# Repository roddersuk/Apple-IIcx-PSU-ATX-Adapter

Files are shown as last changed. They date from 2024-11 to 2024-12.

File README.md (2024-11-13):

# Apple-IIcx-PSU-ATX-Adapter
Apple Mac IIcx PSU ATX Adapter

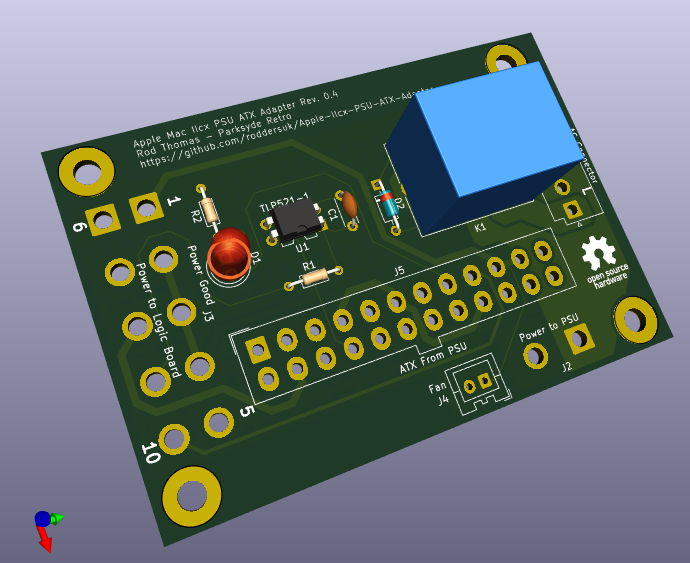
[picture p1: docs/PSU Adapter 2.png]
ATX Adapter PCB

 
The PSU in these old computers suffer with age, particularly the Rifa capacitors which have a tendency to explode.
The general consensus seems to be that it isn't worth trying to repair them as this is likely to only extend their life by a few years.
I therefore decided to replace the guts of the PSU with a mini ATX PSU but there are a couple of issues with hooking it up:
1) The Apple PSU has a special connector to the logic board allowing the PSU to be plugged in as a unit.
2) The ATX PSU does not have direct provision for the soft start capability.
3) Many ATX units don't have a monitor A/C pass-through

I decided to design this PCB to solve all of these issues. It is designed to connect to the power plug from the mains input unit, pass AC power 
to the ATX board, get DC power back via the ATX connector and use the logic board plug and wires from the old PSU.

The ATX PSU I have used is from FSP Group Inc. Model FSP270-60LE as this has comparable power output capabilities.

I have also designed a mounting plate for the ATX PCB which can be 3D printed.

See files in Docs for the schematic and details of the build.

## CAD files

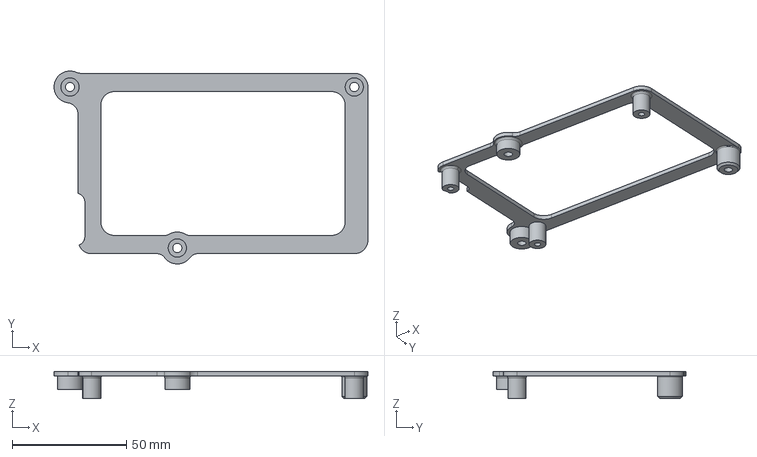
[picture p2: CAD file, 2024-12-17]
PSU Mounting Plate.step
137.5 x 84.5 x 12.0 mm

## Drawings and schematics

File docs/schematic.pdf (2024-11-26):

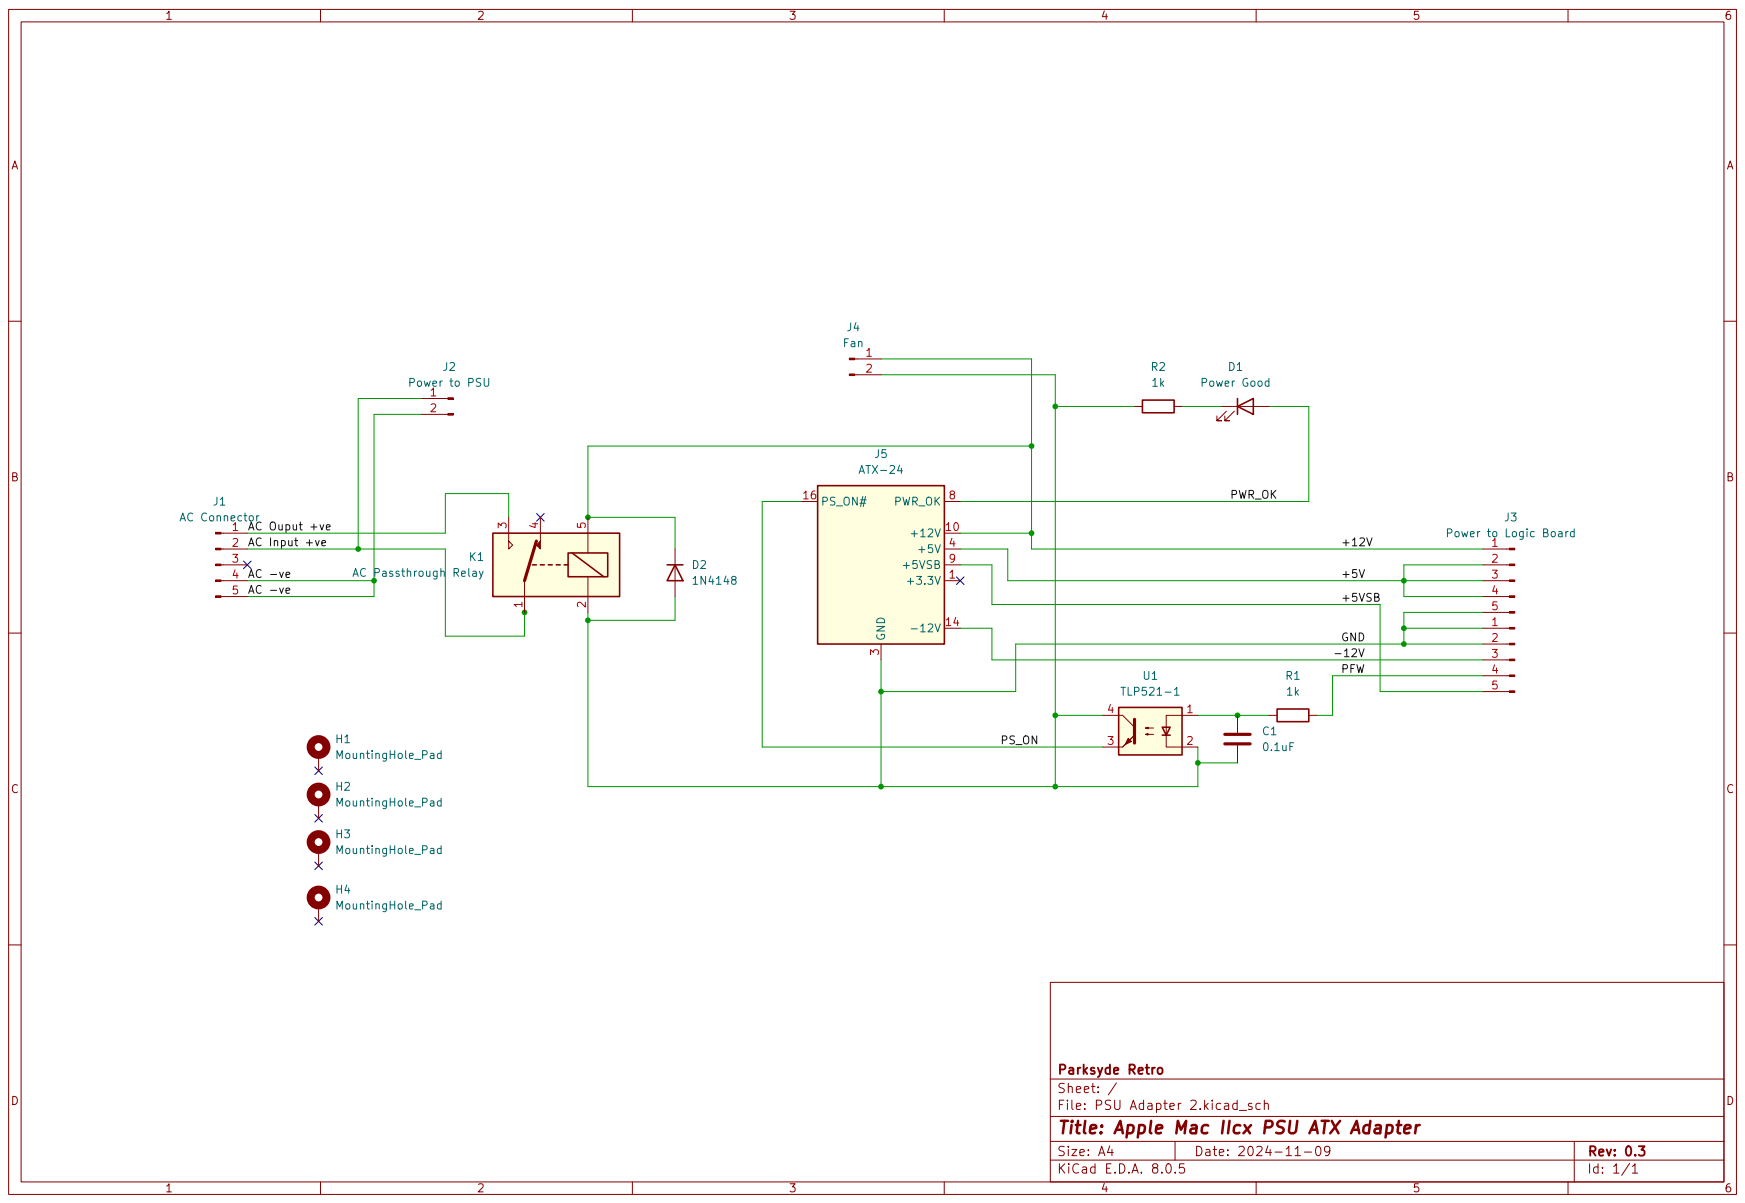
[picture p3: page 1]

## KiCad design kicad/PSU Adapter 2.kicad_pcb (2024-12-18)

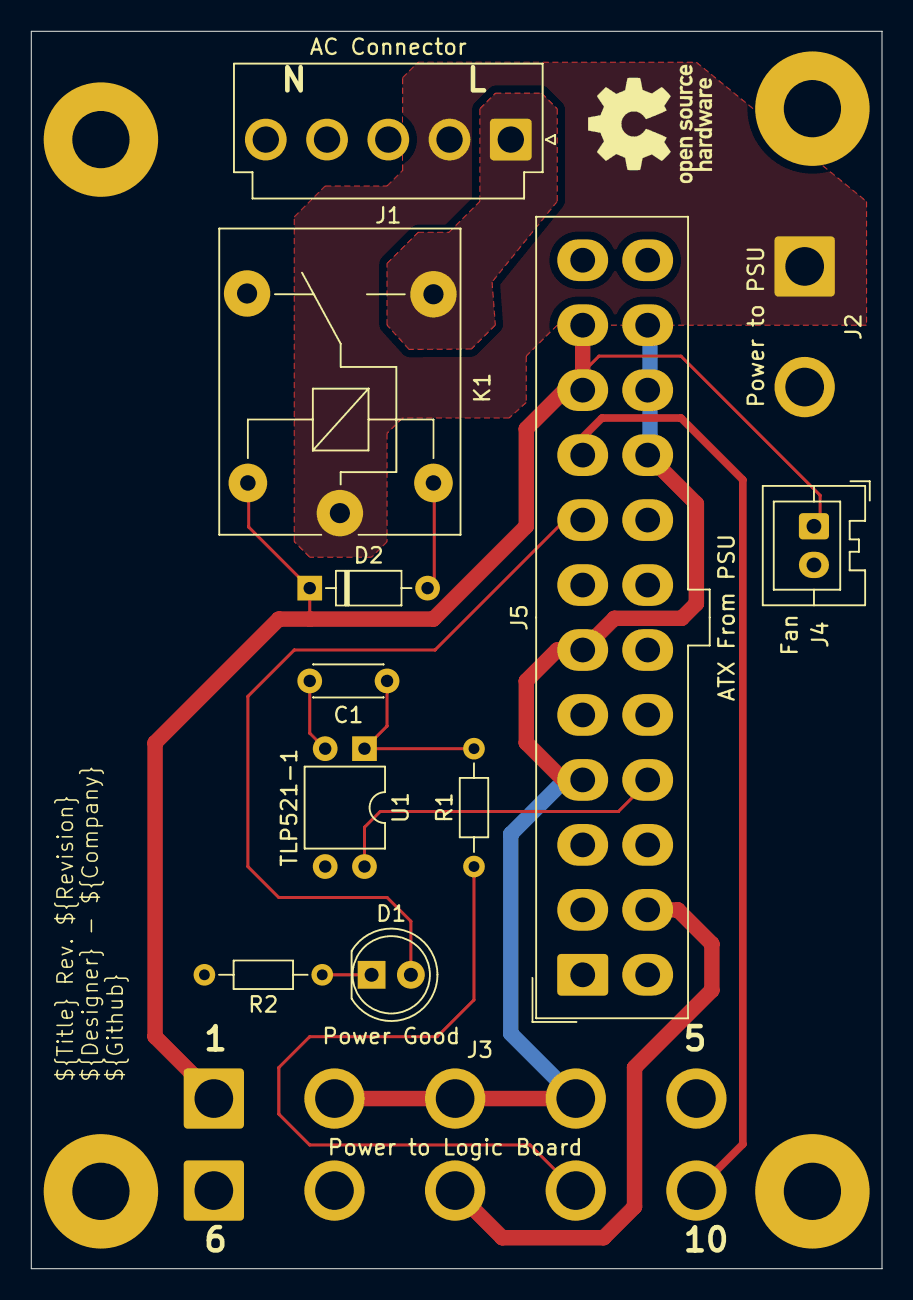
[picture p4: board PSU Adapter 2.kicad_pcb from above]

Board: 2 copper layers, 55.0 x 80.0 mm, 17 parts (0 on the bottom side), 13 nets.

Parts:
C1: 0.1uF; C_Disc_D4.3mm_W1.9mm_P5.00mm
D1: Power Good; LED_D5.0mm
D2: 1N4148; D_DO-35_SOD27_P7.62mm_Horizontal
H1, H2, H3, H4: MountingHole_Pad; MountingHole_3.7mm_Pad
J1: AC Connector; JST_VH_B5P-VH-B_1x05_P3.96mm_Vertical
J2: Power to PSU; SolderWire-2sqmm_1x02_P7.8mm_D2mm_OD3.9mm
J3: Power to Logic Board; SolderWire-2sqmm_1x05_P7.8mm_D2mm_OD3.9mm
J4: Fan; JST_XA_B02B-XASK-1_1x02_P2.50mm_Vertical
J5: ATX From PSU; Molex_Mini-Fit_Jr_5566-24A_2x12_P4.20mm_Vertical_Chinese
J6: Conn_01x05_Pin; SolderWire-2sqmm_1x05_P7.8mm_D2mm_OD3.9mm
K1: AC Passthrough Relay; Relay_SPDT_SANYOU_SRD_Series_Form_C
R1, R2: 1k; R_Axial_DIN0204_L3.6mm_D1.6mm_P7.62mm_Horizontal
U1: TLP521-1; DIP-4_W7.62mm

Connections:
/+5V: J3.2, J3.3, J3.4, J5.4 (+5V), J5.6 (+5V), J5.21 (+5V), J5.22 (+5V), J5.23 (+5V)
/+5VSB: J5.9 (+5VSB), J6.5
/+12V: D2.1 (K), J3.1, J4.1, J5.10 (+12V), J5.11 (+12V), K1.5
/-12V: J5.14 (-12V), J6.3
/AC -ve: J1.4, J1.5, J2.2
/AC Input +ve: J1.2, J2.1, K1.1
/AC Ouput +ve: J1.1, K1.3
/GND: C1.2, D2.2 (A), J3.5, J4.2, J5.3 (GND), J5.5 (GND), J5.7 (GND), J5.15 (GND), J5.17 (GND), J5.18 (GND), J5.19 (GND), J5.24 (GND), J6.1, J6.2, K1.2, R2.2, U1.2, U1.3
/PFW: J6.4, R1.1
/PS_ON: J5.16 (PS_ON#), U1.4
/PWR_OK: D1.2 (A), J5.8 (PWR_OK)
unnamed: C1.1, R1.2, U1.1
unnamed: D1.1 (K), R2.1

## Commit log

2024-11-26 Add files via upload
    Updated to rev 0.3 including footprint for Chinese ATX connector which has 4.2mm pitch between rows (Molex spec is 5.5mm)
    [PSU Adapter 2.kicad_pcb, PSU Adapter 2.kicad_sch]
2024-12-17 Add files via upload
    Increased hole size
2024-12-17 Add files via upload
    Modified ATX connector
    [PSU Adapter 2.kicad_pcb]
2024-12-17 Add files via upload
    Adapter plate to fit ATX PSU in Apple PSU case.
    [PSU Mounting Plate.step]
2024-12-18 Add files via upload
    Fix soft start
    [PSU Adapter 2-B_Cu.gbl, PSU Adapter 2-B_Mask.gbs, PSU Adapter 2-B_Paste.gbp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]
2024-12-18 Add files via upload
    Fix to soft start
    [PSU Adapter 2.kicad_pcb]
